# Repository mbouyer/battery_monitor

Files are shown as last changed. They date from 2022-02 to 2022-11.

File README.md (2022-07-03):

# battery_monitor
12V battery monitoring

This project includes 2 boards for a service 12V Pb battery monitoring.

The main board monitors the battery voltage and current, using a microchip PAC1953 chip and a precision shunt resistor. It uses a pic18f with integrated CAN controller, and connects to a CAN bus network. Along with instant voltage and current values, the pic18f will be able to compute and report the battery SoC. As the PAC1953 has 3 channels, it will also be able to monitor other sources, like solar panel or the engine battery. The main battery will be monitored with an external, high current shunt resistor (100A/50mV) so one of the on-board shunt resitor won't be soldered.

The second board will convert the voltage across the high current shunt resistor to a voltage (between 0.5 and 4.5V) suitable to drive a pannel-mounted Osculati  +/-50A ampmeter(27.320.23). As I don't expect to have currents more than 20A here, I computed the gain so that the indicator range is +/-25A (that is, the indicated value will be twice the real value). Two potentiometers allows to adjust the 0 and the gain. This, along with an external analog voltmeter, provides a second, independant battery monitoring tool.

car battery, engine and solar panel icons by [Icons8](https://icons8.com)

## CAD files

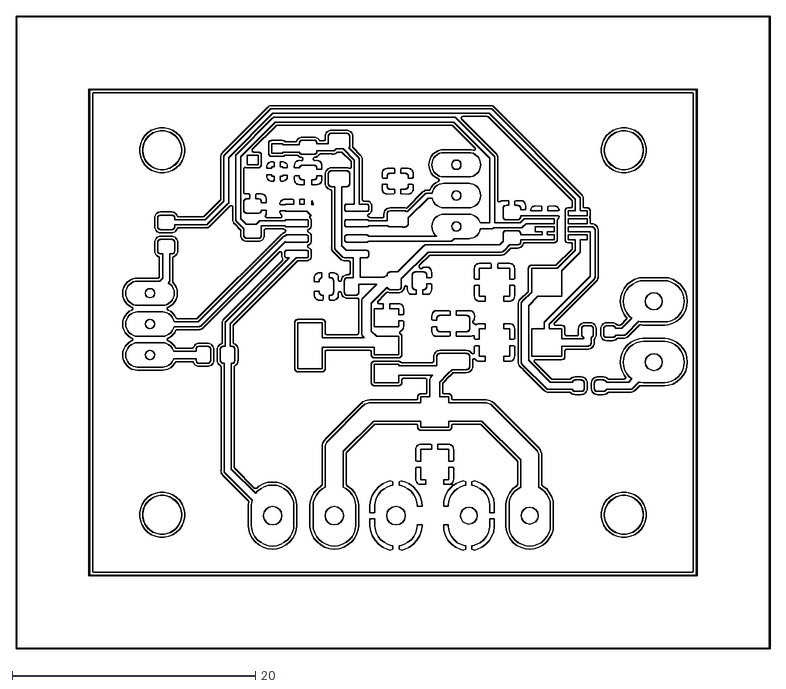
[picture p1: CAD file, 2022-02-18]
hardware/CAD/osculati_amperemetre_sensor-B_Cu.dxf
62.1 x 52.1

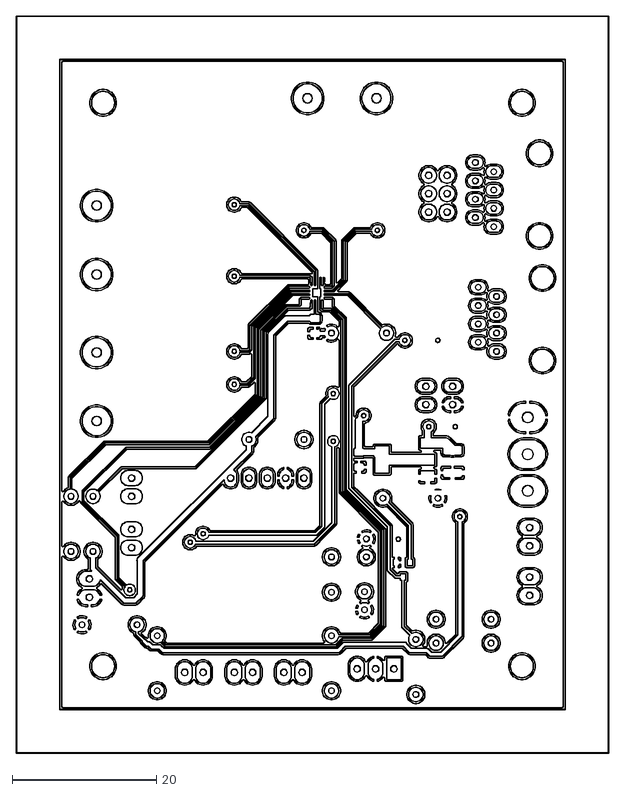
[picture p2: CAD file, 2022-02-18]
hardware/CAD/battery_can_monitor-F_Cu.dxf
82.1 x 102.1

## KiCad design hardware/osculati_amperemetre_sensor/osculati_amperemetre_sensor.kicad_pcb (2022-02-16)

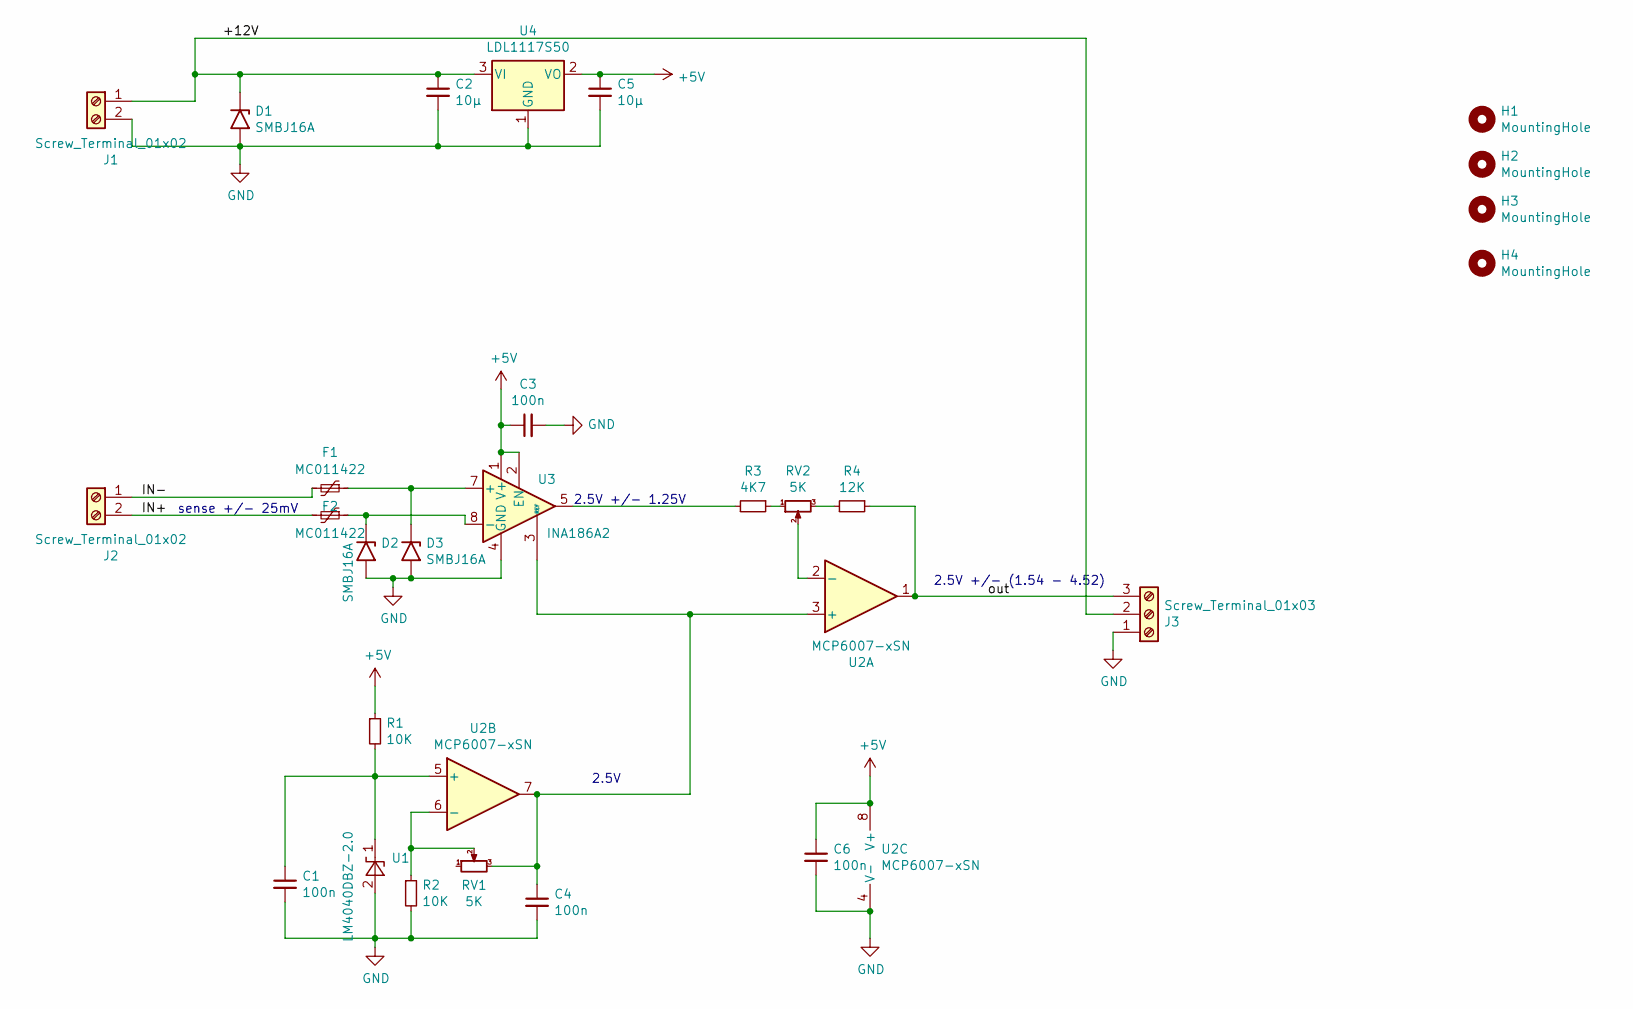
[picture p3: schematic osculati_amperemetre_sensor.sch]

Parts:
C1, C3, C4, C6: 100n; C_0805_2012Metric_Pad1.18x1.45mm_HandSolder
C2: 10µ; C_1210_3225Metric_Pad1.33x2.70mm_HandSolder
C5: 10µ; C_0805_2012Metric_Pad1.18x1.45mm_HandSolder
D1, D2, D3: SMBJ16A; D_SMB
F1, F2: MC011422; R_0603_1608Metric_Pad0.98x0.95mm_HandSolder
H1, H2, H3, H4: MountingHole; MountingHole_3.2mm_M3_DIN965
J1, J2: Screw_Terminal_01x02; MC24356
J3: Screw_Terminal_01x03; TerminalBlock_bornier-3_P5.08mm
R1, R2: 10K; R_1206_3216Metric_Pad1.30x1.75mm_HandSolder
R3: 4K7; R_0805_2012Metric_Pad1.20x1.40mm_HandSolder
R4: 12K; R_0805_2012Metric_Pad1.20x1.40mm_HandSolder
RV1, RV2: 5K; T93XA
U1: LM4040DBZ-2.0; SOT-23
U2: MCP6007-xSN; SOIC-8_3.9x4.9mm_P1.27mm
U3: INA186A2; SOT-23-8_Handsoldering
U4: LDL1117S50; SOT-223-3_TabPin2

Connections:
+5V: C3.1, C5.1, C6.1, R1.1, U2.8 (V+), U3.1 (V+), U3.2 (EN), U4.2 (VO)
/+12V: C2.1, D1.1 (A1), J1.1, J3.2, U4.3 (VI)
/IN+: F2.2, J2.2
/IN-: F1.2, J2.1
/out: J3.3, R4.1, U2.1
GND: C1.2, C2.2, C3.2, C4.2, C5.2, C6.2, D1.2 (A2), D2.2 (A2), D3.2 (A2), J1.2, J3.1, R2.2, U1.2 (A), U2.4 (V-), U3.4 (GND), U4.1 (GND)
unnamed: C1.1, R1.2, U1.1 (K), U2.5 (+)
unnamed: C4.1, RV1.3, U2.3 (+), U2.7, U3.3 (REF)
unnamed: D2.1 (A1), F2.1, U3.8 (-)
unnamed: D3.1 (A1), F1.1, U3.7 (+)
unnamed: R2.1, RV1.2, U2.6 (-)
unnamed: R3.1, RV2.1
unnamed: R3.2, U3.5
unnamed: R4.2, RV2.3
unnamed: RV2.2, U2.2 (-)

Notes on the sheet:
sense +/- 25mV
2.5V
2.5V +/- 1.25V
2.5V +/- (1.54 - 4.52)

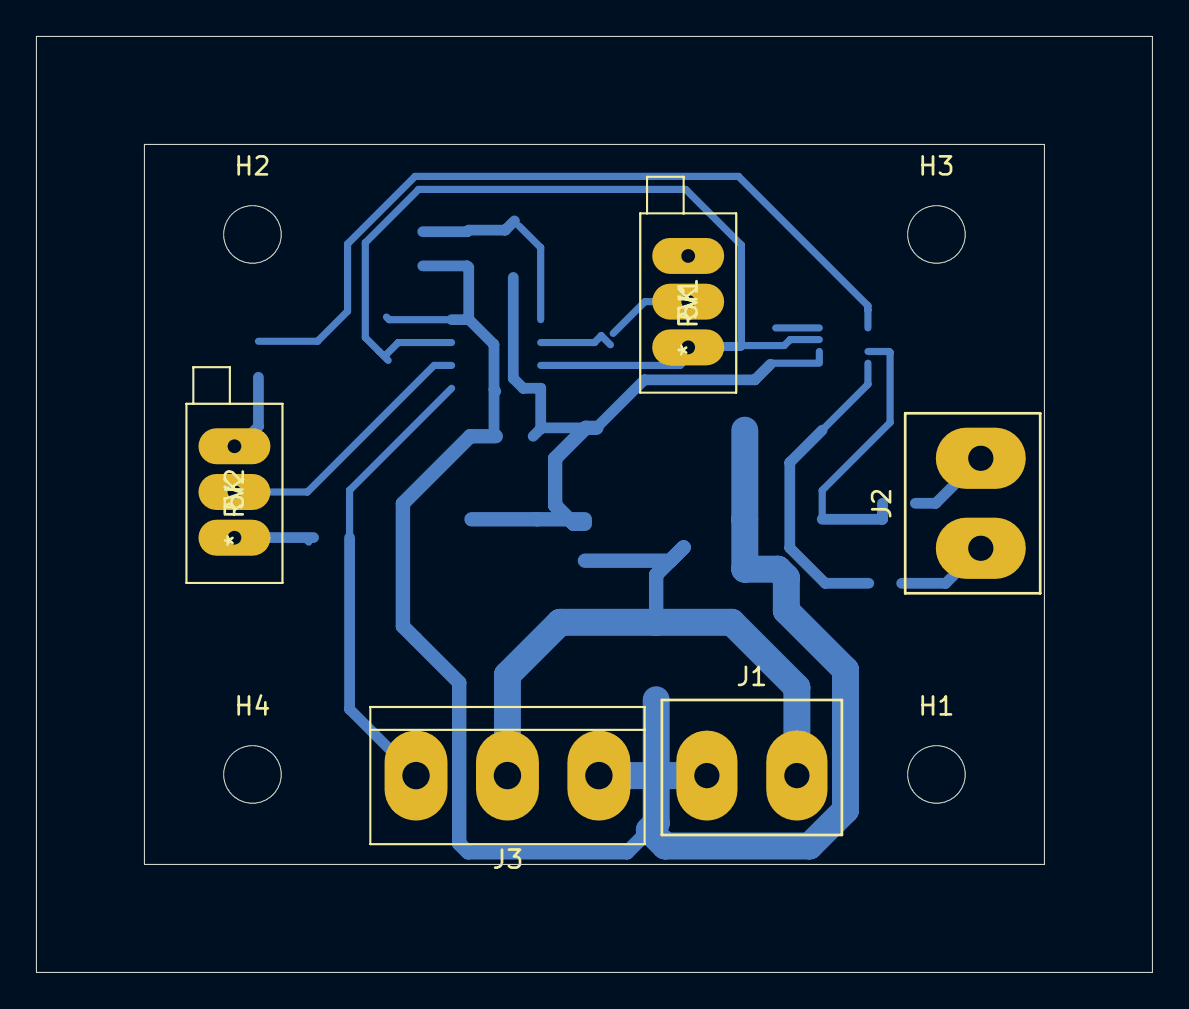
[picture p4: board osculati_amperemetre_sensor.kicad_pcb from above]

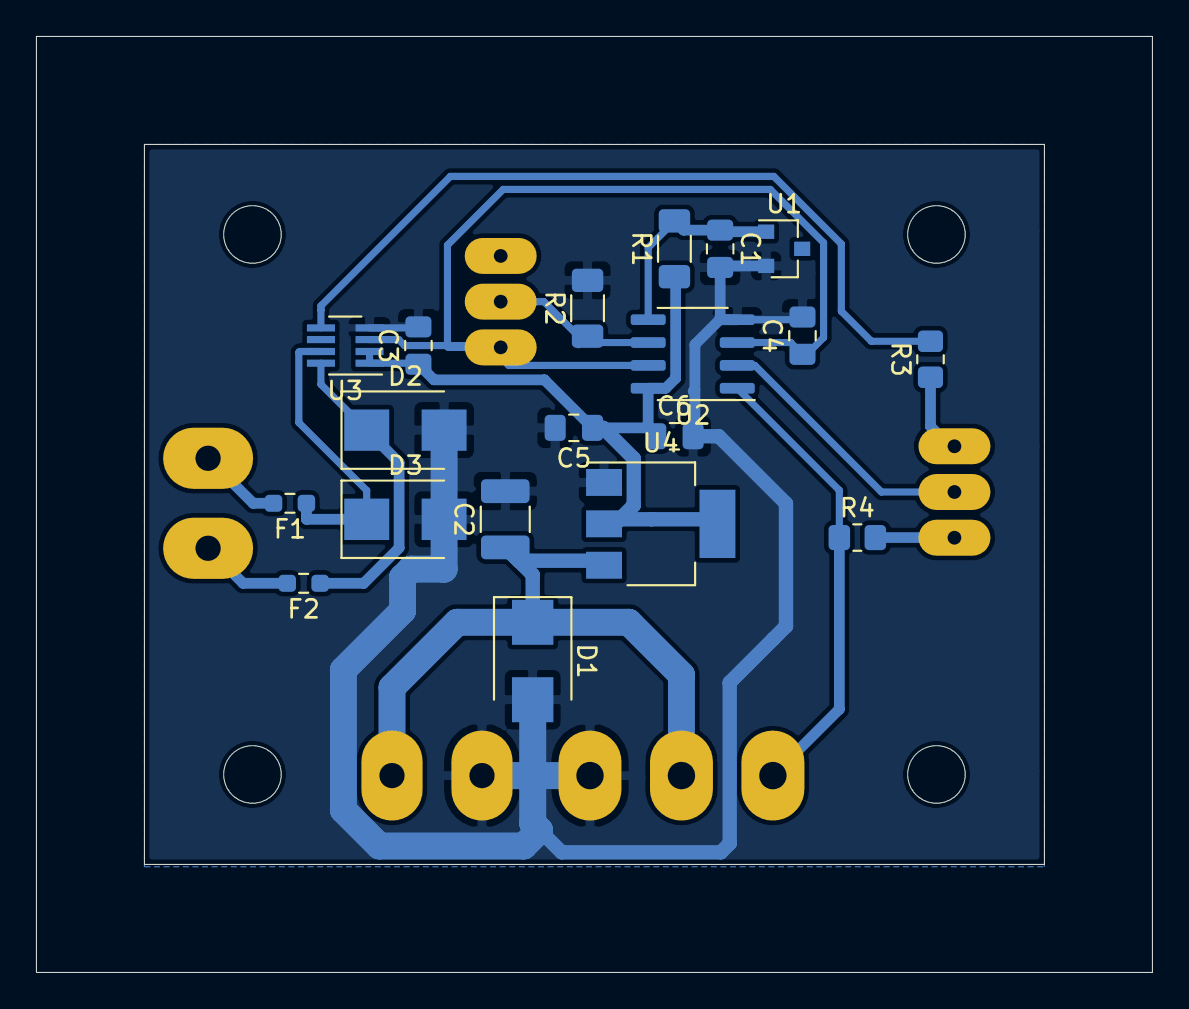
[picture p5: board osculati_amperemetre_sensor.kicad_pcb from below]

Board: 2 copper layers, 62.0 x 52.0 mm, 28 parts (19 on the bottom side), 15 nets.

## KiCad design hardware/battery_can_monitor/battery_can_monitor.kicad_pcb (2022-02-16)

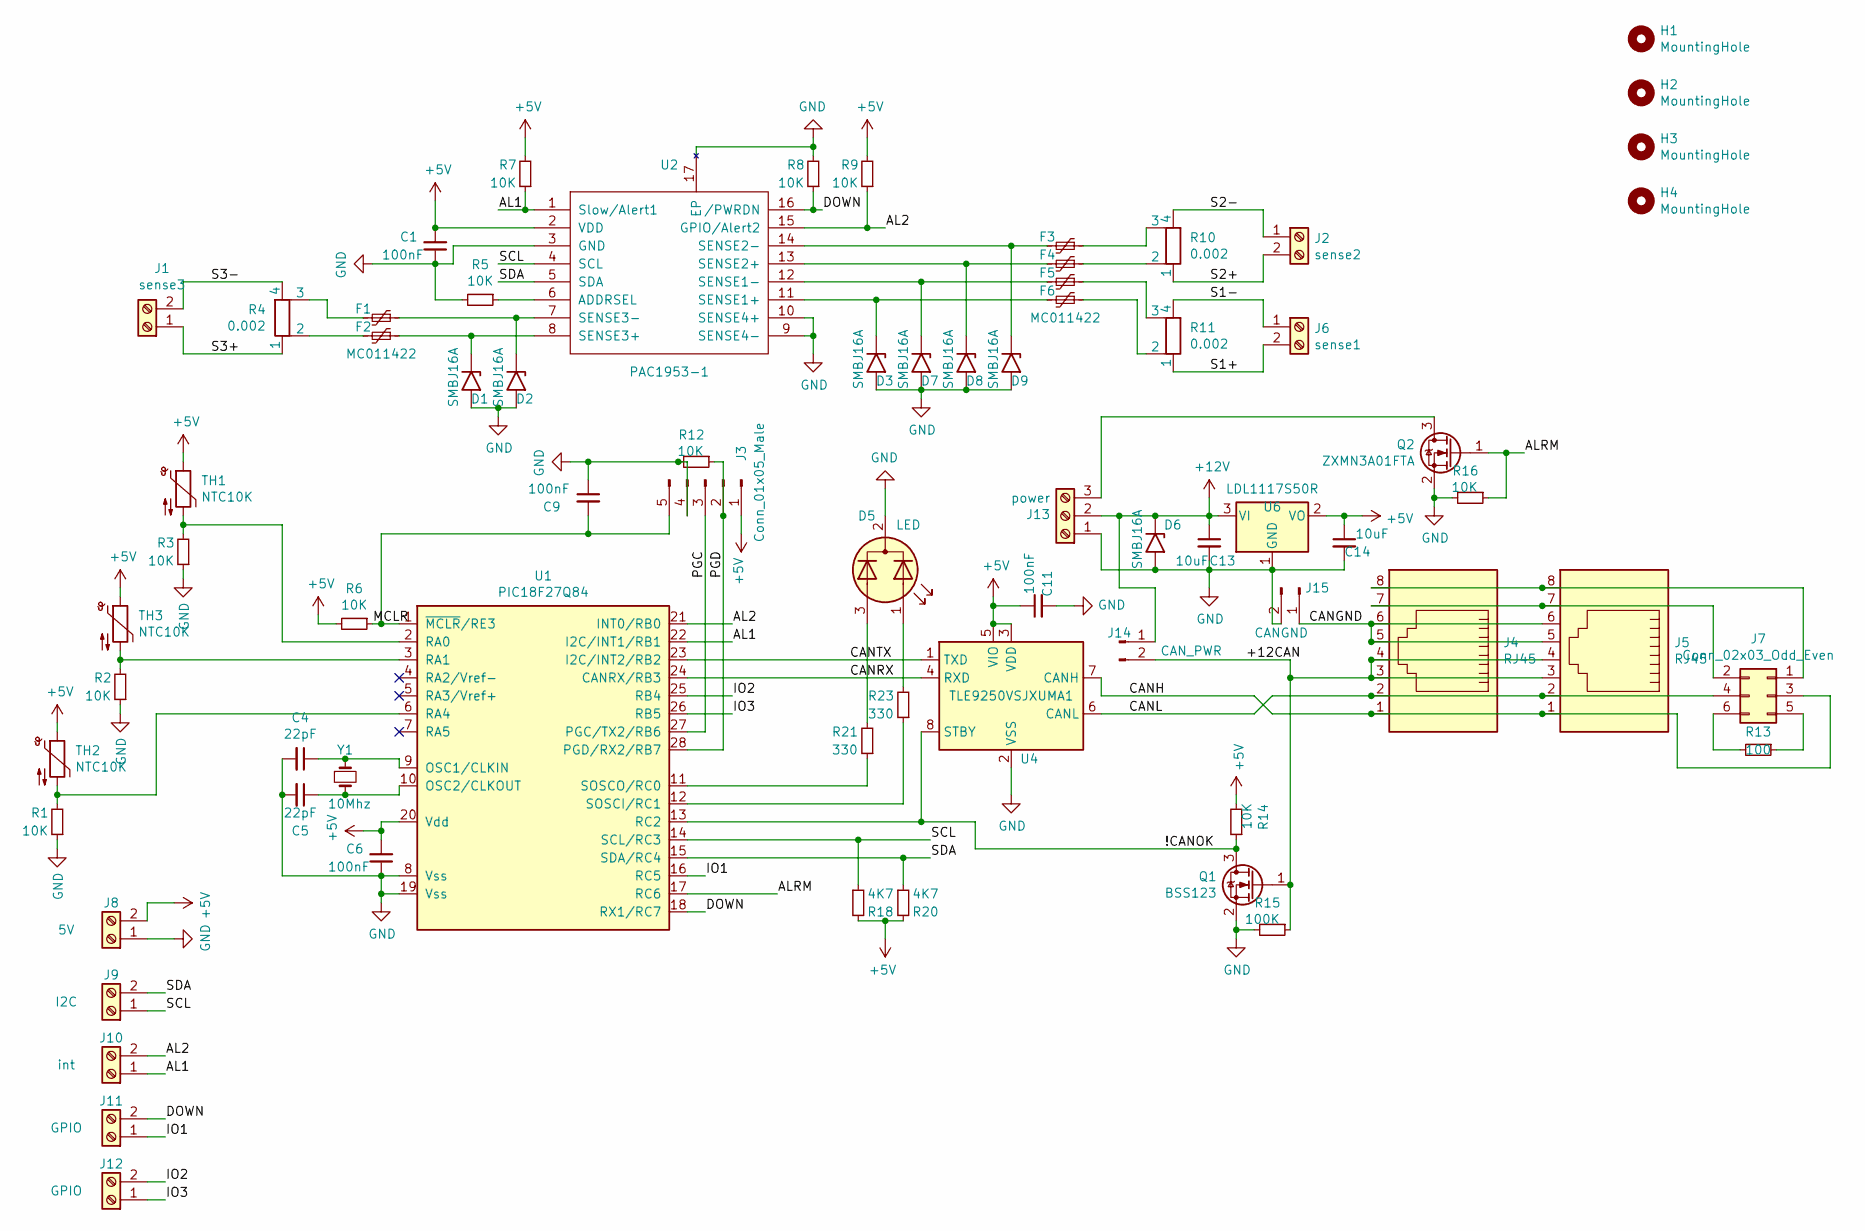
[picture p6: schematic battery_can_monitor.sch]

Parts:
C1, C6, C9, C11: 100nF; C_0805_2012Metric_Pad1.18x1.45mm_HandSolder
C4, C5: 22pF; C_Disc_D3.8mm_W2.6mm_P2.50mm
C13: 10uF; C_1210_3225Metric_Pad1.33x2.70mm_HandSolder
C14: 10uF; C_0805_2012Metric_Pad1.18x1.45mm_HandSolder
D1, D2, D3, D6, D7, D8, D9: SMBJ16A; D_SMB_Handsoldering
D5: LED; LED_D3.0mm-3
F1, F2, F3, F4, F5, F6: MC011422; R_0603_1608Metric_Pad0.98x0.95mm_HandSolder
H1, H2, H3, H4: MountingHole; MountingHole_3.2mm_M3_DIN965
J1: sense3; TerminalBlock_MetzConnect_Type703_RT10N02HGLU_1x02_P9.52mm_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
J2: sense2; TerminalBlock_MetzConnect_Type703_RT10N02HGLU_1x02_P9.52mm_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
J3: Conn_01x05_Male; PinHeader_1x05_P2.54mm_Vertical
J4, J5: RJ45; RJ45_Amphenol_54602-x08_Horizontal
J6: sense1; TerminalBlock_MetzConnect_Type703_RT10N02HGLU_1x02_P9.52mm_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
J7: Conn_02x03_Odd_Even; PinHeader_2x03_P2.54mm_Vertical
J8: 5V; TerminalBlock_TE_282834-2_1x02_P2.54mm_Horizontal
J9: I2C; TerminalBlock_TE_282834-2_1x02_P2.54mm_Horizontal
J10: int; TerminalBlock_TE_282834-2_1x02_P2.54mm_Horizontal
J11, J12: GPIO; TerminalBlock_TE_282834-2_1x02_P2.54mm_Horizontal
J13: power; TerminalBlock_bornier-3_P5.08mm
J14: CAN_PWR; PinHeader_1x02_P2.54mm_Vertical
J15: CANGND; PinHeader_1x02_P2.54mm_Vertical
Q1: BSS123; SOT-23
Q2: ZXMN3A01FTA; SOT-23
R1, R2, R3, R8, R12: 10K; R_1206_3216Metric_Pad1.30x1.75mm_HandSolder
R4, R10, R11: 0.002; R-Shunt_2512_6332Metric_Pad1.40x3.35mm_HandSolder
R5, R6, R7, R9, R14, R16: 10K; R_Axial_DIN0207_L6.3mm_D2.5mm_P7.62mm_Horizontal
R13: 100; R_0805_2012Metric_Pad1.20x1.40mm_HandSolder
R15: 100K; R_Axial_DIN0207_L6.3mm_D2.5mm_P7.62mm_Horizontal
R18, R20: 4K7; R_Axial_DIN0207_L6.3mm_D2.5mm_P7.62mm_Horizontal
R21, R23: 330; R_Axial_DIN0207_L6.3mm_D2.5mm_P7.62mm_Horizontal
TH1, TH2, TH3: NTC10K; TerminalBlock_TE_282834-2_1x02_P2.54mm_Horizontal
U1: PIC18F27Q84; SOIC-28W_7.5x17.9mm_P1.27mm
U2: PAC1953-1; VQFN-16-1EP_3x3mm_P0.5mm_EP1.1x1.1mm
U4: TLE9250VSJXUMA1; SOIC-8_3.9x4.9mm_P1.27mm
U6: LDL1117S50R; SOT-223-3_TabPin2
Y1: 10Mhz; Crystal_HC18-U_Vertical

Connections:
+5V: C1.2, C6.2, C11.1, C14.1, J3.1, J8.2, R6.2, R7.2, R9.2, R14.2, R18.2, R20.2, TH1.1, TH2.1, TH3.1, U1.20 (Vdd), U2.2 (VDD), U4.3 (VDD), U4.5 (VIO), U6.2 (VO)
+12V: C13.1, D6.1 (A1), J13.2, J14.1, U6.3 (VI)
/!CANOK: Q1.3 (D), R14.1, U1.13 (RC2), U4.8 (STBY)
/+12CAN: J4.3, J4.4, J5.3, J5.4, J14.2, Q1.1 (G), R15.1
/AL1: J10.1, R7.1, U1.22 (I2C/INT1/RB1), U2.1 (Slow/Alert1)
/AL2: J10.2, R9.1, U1.21 (INT0/RB0), U2.15 (GPIO/Alert2)
/ALRM: Q2.1 (G), R16.1, U1.17 (RC6)
/CANGND: J4.5, J4.6, J5.5, J5.6, J15.1
/CANH: J4.1, J5.1, J7.3, U4.7 (CANH)
/CANL: J4.2, J5.2, J7.4, U4.6 (CANL)
/CANRX: U1.24 (CANRX/RB3), U4.4 (RXD)
/CANTX: U1.23 (I2C/INT2/RB2), U4.1 (TXD)
/DOWN: J11.2, R8.1, U1.18 (RX1/RC7), U2.16 (/PWRDN)
/IO1: J11.1, U1.16 (RC5)
/IO2: J12.2, U1.25 (RB4)
/IO3: J12.1, U1.26 (RB5)
/MCLR: C9.2, J3.5, R6.1, U1.1 (~MCLR~/RE3)
/PGC: J3.3, U1.27 (PGC/TX2/RB6)
/PGD: J3.2, R12.1, U1.28 (PGD/RX2/RB7)
/S1+: J6.2, R11.1
/S1-: J6.1, R11.4
/S2+: J2.2, R10.1
/S2-: J2.1, R10.4
/S3+: J1.1, R4.1
/S3-: J1.2, R4.4
/SCL: J9.1, R18.1, U1.14 (SCL/RC3), U2.4 (SCL)
/SDA: J9.2, R20.1, U1.15 (SDA/RC4), U2.5 (SDA)
GND: C1.1, C4.2, C5.2, C6.1, C9.1, C11.2, C13.2, C14.2, D1.2 (A2), D2.2 (A2), D3.2 (A2), D5.2 (K), D6.2 (A2), D7.2 (A2), D8.2 (A2), D9.2 (A2), J3.4, J8.1, J13.1, J15.2, Q1.2 (S), Q2.2 (S), R1.1, R2.1, R3.1, R5.2, R8.2, R12.2, R15.2, R16.2, U1.8 (Vss), U1.19 (Vss), U2.3 (GND), U2.9 (SENSE4-), U2.10 (SENSE4+), U2.17 (EP), U4.2 (VSS), U4.9 (VSS), U6.1 (GND)
unnamed: C4.1, U1.9 (OSC1/CLKIN), Y1.1
unnamed: C5.1, U1.10 (OSC2/CLKOUT), Y1.2
unnamed: D1.1 (A1), F2.1, U2.8 (SENSE3+)
unnamed: D2.1 (A1), F1.1, U2.7 (SENSE3-)
unnamed: D3.1 (A1), F6.2, U2.11 (SENSE1+)
unnamed: D5.1 (A1), R23.2
unnamed: D5.3 (A2), R21.2
unnamed: D7.1 (A1), F5.2, U2.12 (SENSE1-)
unnamed: D8.1 (A1), F4.2, U2.13 (SENSE2+)
unnamed: D9.1 (A1), F3.2, U2.14 (SENSE2-)
unnamed: F1.2, R4.3
unnamed: F2.2, R4.2
unnamed: F3.1, R10.3
unnamed: F4.1, R10.2
unnamed: F5.1, R11.3
unnamed: F6.1, R11.2
unnamed: J4.7, J5.7, J7.2
unnamed: J4.8, J5.8, J7.1
unnamed: J7.5, R13.1
unnamed: J7.6, R13.2
unnamed: J13.3, Q2.3 (D)
unnamed: R1.2, TH2.2, U1.6 (RA4)
unnamed: R2.2, TH3.2, U1.3 (RA1)
unnamed: R3.2, TH1.2, U1.2 (RA0)
unnamed: R5.1, U2.6 (ADDRSEL)
unnamed: R21.1, U1.11 (SOSCO/RC0)
unnamed: R23.1, U1.12 (SOSCI/RC1)

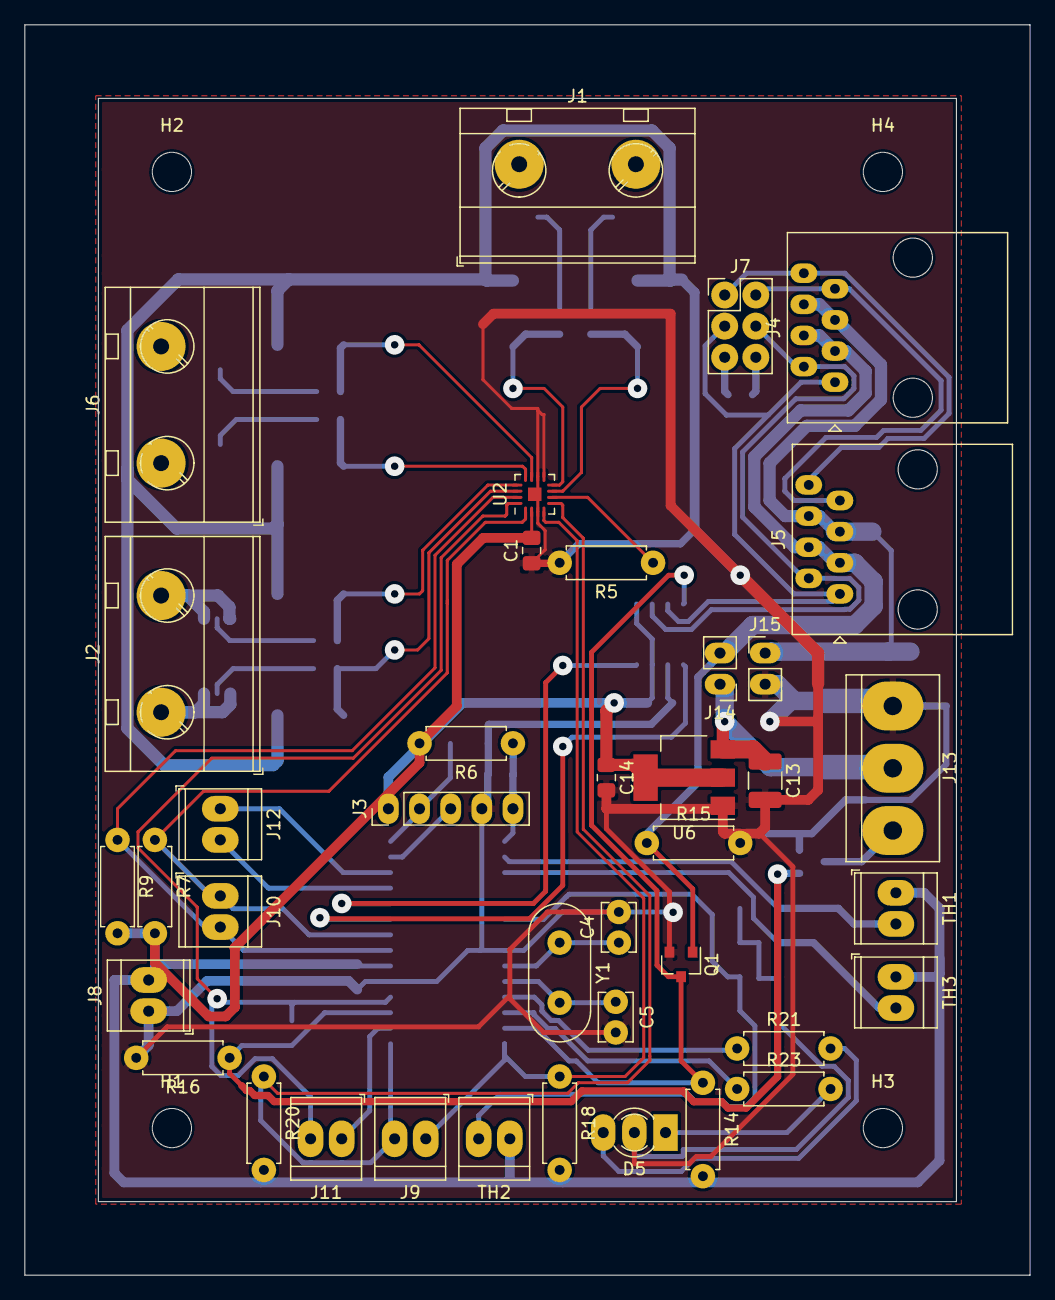
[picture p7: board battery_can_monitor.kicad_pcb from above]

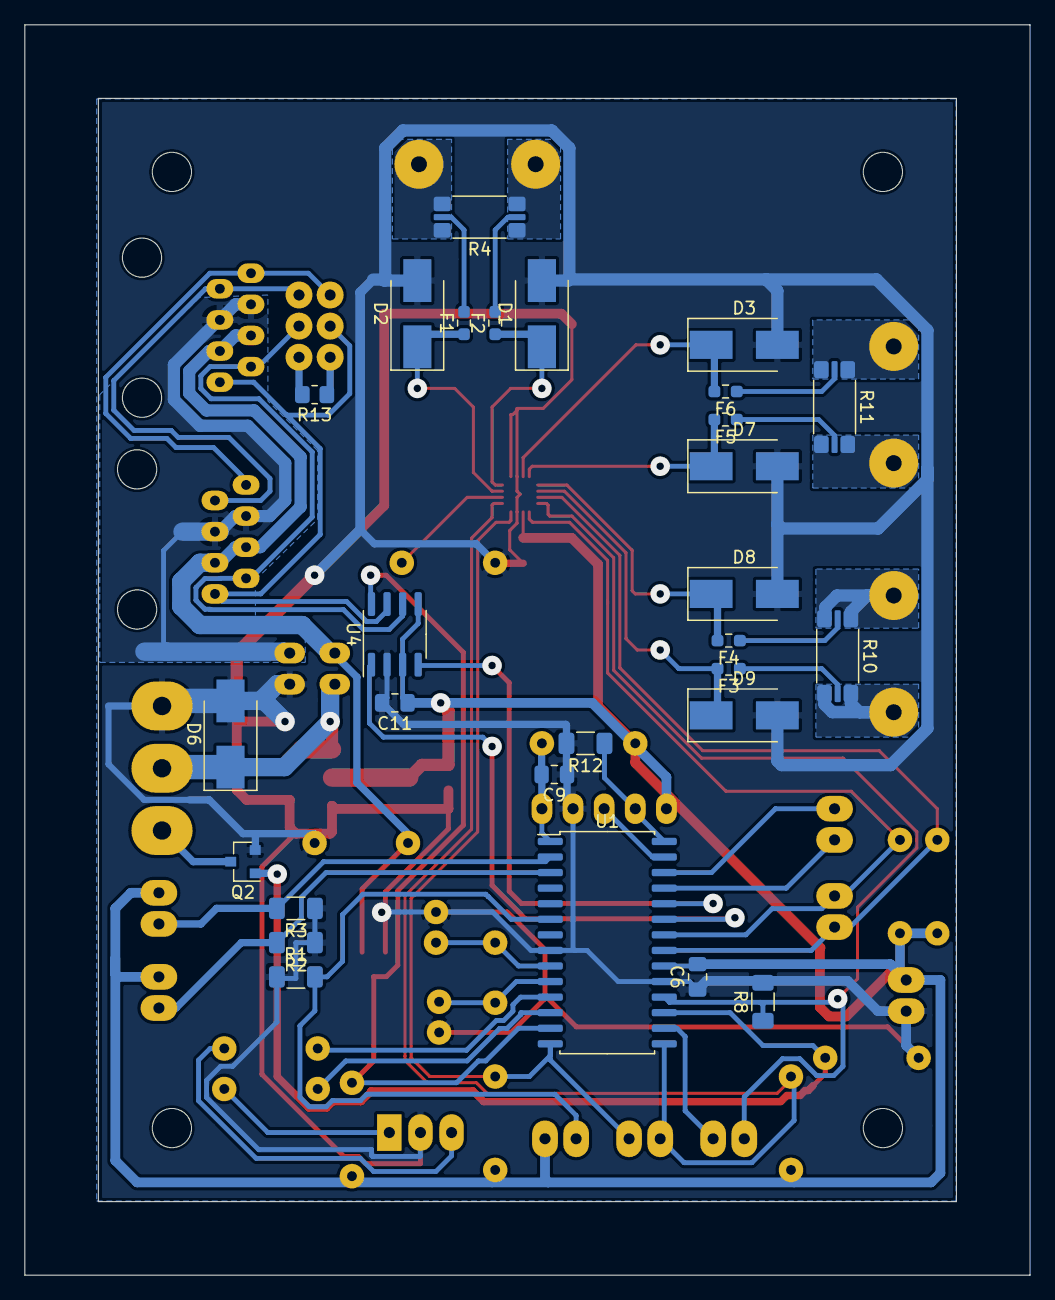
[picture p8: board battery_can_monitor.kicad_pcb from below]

Board: 2 copper layers, 82.0 x 102.0 mm, 71 parts (28 on the bottom side), 55 nets.

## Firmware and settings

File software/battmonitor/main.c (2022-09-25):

/* $Id: main.c,v 1.36 2019/03/12 19:24:19 bouyer Exp $ */
/*
 * Copyright (c) 2022 Manuel Bouyer
 *
 * All rights reserved.
 *
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
 * THIS SOFTWARE IS PROVIDED BY THE NETBSD FOUNDATION, INC. AND CONTRIBUTORS
 * ``AS IS'' AND ANY EXPRESS OR IMPLIED WARRANTIES, INCLUDING, BUT NOT LIMITED
 * TO, THE IMPLIED WARRANTIES OF MERCHANTABILITY AND FITNESS FOR A PARTICULAR
 * PURPOSE ARE DISCLAIMED.  IN NO EVENT SHALL THE FOUNDATION OR CONTRIBUTORS
 * BE LIABLE FOR ANY DIRECT, INDIRECT, INCIDENTAL, SPECIAL, EXEMPLARY, OR
 * CONSEQUENTIAL DAMAGES (INCLUDING, BUT NOT LIMITED TO, PROCUREMENT OF
 * SUBSTITUTE GOODS OR SERVICES; LOSS OF USE, DATA, OR PROFITS; OR BUSINESS
 * INTERRUPTION) HOWEVER CAUSED AND ON ANY THEORY OF LIABILITY, WHETHER IN
 * CONTRACT, STRICT LIABILITY, OR TORT (INCLUDING NEGLIGENCE OR OTHERWISE)
 * ARISING IN ANY WAY OUT OF THE USE OF THIS SOFTWARE, EVEN IF ADVISED OF THE
 * POSSIBILITY OF SUCH DAMAGE.
 */

#include <xc.h>
#include <stdio.h> 
#include <string.h> 
#include <stdlib.h> 
#include <nmea2000.h>
#include <nmea2000_pgn.h>
#include <raddeg.h>
#include "serial.h"
#include "i2c.h"
#include "ntc_tab.h"
#include "pac195x.h"

unsigned int devid, revid; 

unsigned long nmea2000_user_id; 

static unsigned char sid;

static struct nmea2000_msg msg;
static unsigned char nmea2000_data[NMEA2000_DATA_FASTLENGTH];

unsigned int timer0_read(void);

#define TIMER0_5MS 48
#define TIMER0_1MS 10

#define LEDBATT_R LATCbits.LATC0
#define LEDBATT_G LATCbits.LATC1

#define NDOWN LATCbits.LATC7
#define NCANOK PORTCbits.RC2

static char counter_10hz;
static char counter_1hz;
static uint16_t seconds;
static volatile union softintrs {
	struct softintrs_bits {
		char int_10hz : 1;	/* 0.1s timer */
	} bits;
	char byte;
} softintrs;

static uint16_t a2d_acc;

#define PAC_I2C_ADDR 0x2e

int16_t batt_v[4];
int16_t batt_i[4];
uint16_t batt_temp[4];

static int32_t voltages_acc[4];
pac_ctrl_t pac_ctrl;

/* for journal */
static int64_t l600_current_acc[4];
static __uint24 l600_current_count;
static uint32_t l600_voltages_acc[4];

/*
 * journal data structure (record every 10mn)
 * For current, in mA: 18 bits, including sign
 * voltage, max 20.47V needs 11 bits
 * temperature -40C to 60C: 8 bits (K - 233)
 * valid: 1bit
 * instance: 2 bits
 =>  total 40 bits, or 5 bytes
 51 entries per block of 256 bytes: 1 bytes free (for block flags)
 In 32k flash, 128 blocks -> 6528 entries, or 272 hours (11 days)
   with 4 channels active
 */

union log_entry {
	uint8_t data[5];
	struct {
		uint8_t temp;
		uint8_t u_low; /* low bits of voltage */
		uint16_t i_low; /* low bits current */
		uint8_t u_high : 3; /* high bits of voltage */
		uint8_t nvalid : 1; /* 0 = entry valid */
		uint8_t i_high: 2; /* high bits of current */
		uint8_t instance: 2; /* batt instance */
	} s;
};

#define LOG_ENTRIES 51

struct log_block {
	union log_entry b_entry[LOG_ENTRIES];
	uint8_t b_flags;
#define B_FILL_STAT 0x03
#define B_FILL_FREE 0x03
#define B_FILL_PART 0x01
#define B_FILL_FULL 0x00
#define B_FILL_GEN  0xfc
};

#define LOG_BLOCKS ((uint8_t)128)
#define LOG_BLOCKS_MASK (LOG_BLOCKS - 1)

extern const struct log_block battlog[LOG_BLOCKS] __at(0x18000);

extern struct log_block curlog __at(0x3700);

/* current log entry (to be updated) */
uint8_t log_cblk;
uint8_t log_centry;
uint8_t log_gen;

/* log requests/replies */
uint8_t logreq_len;
uint8_t logreq_id; /* current id for fast frame */

union __packed {
	uint8_t _data[233 + 8];
	struct private_log_request rq;
	struct private_log_reply rp;
	struct private_log_error er;
	struct private_log_reset rst;
} private_log_cmd;
static unsigned char fastid;

static inline void
utolog(uint16_t u, union log_entry *e)
{
	e->s.u_low = u & 0xff;
	e->s.u_high = (u >> 8) & 0x7;
}

static inline uint16_t
logtou(union log_entry *e)
{
	uint16_t u;

	u = e->s.u_low;
	u |= (uint16_t)(e->s.u_high & 0x7) << 8;
	return u;
}

static inline void
itolog(int64_t i, union log_entry *e)
{
	e->s.i_low = i & 0xffff;
	e->s.i_high = (i >> 16) & 0x3;
}

static inline int32_t
logtoi(union log_entry *e)
{
	int32_t i;
	i = e->s.i_low;
	i |= (uint32_t)(e->s.i_high & 0x3) << 16;
	if (e->s.i_high & 0x2) {
		i |= 0xfffe0000;
	}
	return i;
}

static void
page_erase(__uint24 addr)
{
	uint8_t err = 0;

	printf("erase 0x%lx\n", (uint32_t)addr);

	NVMADR = addr;
	NVMCON1bits.CMD = 0x06;
	INTCON0bits.GIE = 0;

	NVMLOCK = 0x55;
	NVMLOCK = 0xAA;
	NVMCON0bits.GO = 1;

	while (NVMCON0bits.GO)
		; /* wait */

	if (NVMCON1bits.WRERR) {
		err++;
	}
	NVMCON1bits.CMD = 0;
	INTCON0bits.GIE = 1;
	if (err) {
		printf("erase 0x%lx failed\n", (uint32_t)addr);
	}
}

static void
page_read(__uint24 addr)
{
	uint8_t err = 0;

	printf("read 0x%lx\n", (uint32_t)addr);

	NVMADR = addr;
	NVMCON1bits.CMD = 0x02;
	NVMCON0bits.GO = 1;

	while (NVMCON0bits.GO)
		; /* wait */

	NVMCON1bits.CMD = 0;
}

static void
page_write(__uint24 addr)
{
	uint8_t err = 0;

	printf("write 0x%lx\n", (uint32_t)addr);

	NVMADR = addr;
	NVMCON1bits.CMD = 0x05;
	INTCON0bits.GIE = 0;

	NVMLOCK = 0x55;
	NVMLOCK = 0xAA;
	NVMCON0bits.GO = 1;

	while (NVMCON0bits.GO)
		; /* wait */

	if (NVMCON1bits.WRERR) {
		err++;
	}
	NVMCON1bits.CMD = 0;
	INTCON0bits.GIE = 1;
	if (err) {
		printf("write 0x%lx failed\n", (uint32_t)addr);
	}
}

static void
next_log_entry(void)
{
	printf("write log entry %d/%d\n", log_cblk, log_centry);
	/* mark entry as valid */
	curlog.b_entry[log_centry].s.nvalid = 0;
	curlog.b_flags = log_gen | B_FILL_PART;
	log_centry++;
	if (log_centry == LOG_ENTRIES) {
		/* next block */
		/* write current block */
		curlog.b_flags = log_gen | B_FILL_FULL;
		page_write(&battlog[log_cblk]);
		/* point to next block */
		log_cblk = (log_cblk + 1) & LOG_BLOCKS_MASK;
		log_centry = 0;
		if (log_cblk == 0) /* rollover; update gen number */
			log_gen += 0x4;
		/* erase and load new block */
		page_erase(&battlog[log_cblk]);
		page_read(&battlog[log_cblk]);
	} else {
		/* update current block */
		page_write(&battlog[log_cblk]);
	}
}

static void
log_erase(void)
{
	for (uint8_t c = 0; c < LOG_BLOCKS; c++) {
		page_erase(&battlog[c]);
	}
	log_cblk = log_centry = log_gen = 0;
}

static void
update_log(void)
{
	char c;
	double v;
	int32_t v_i;

	for (c = 0; c < 4; c++) {
		printf("log entry %d/%d ", log_cblk, log_centry);
		if ((pac_ctrl.ctrl_chan_dis & (8 >> c)) != 0)
			continue;
		/* batt_i = acc_value * 0.00075 * 1000 */
		v = (double)l600_current_acc[c] * 0.75 / l600_current_count;
		/* adjust with calibration data */
		switch(c) {
		case 0:
			v = v * 0.988689144013892;
			break;
		case 1:
			v = v * 1.00930129713152;
			break;
		case 2:
			v = v * 4.06331342566096;
			break;
		}
		v_i = v + 0.5;
		printf(" %d %4.4fA %ld", c, v / 1000, v_i);
		itolog(v_i, &curlog.b_entry[log_centry]);
		/* volt = vbus * 0.000488 */
		/* batt_v = voltages_acc * 0.000488 * 100 / 6000; */
		/* adjust by 0.99955132 from calibration data */
		v = (double)l600_voltages_acc[c] * 0.000008129684;
		v_i = v + 0.5;
		printf(" %4.3fV %ld", v / 100, v_i);
		utolog(v_i, &curlog.b_entry[log_centry]);
		curlog.b_entry[log_centry].s.instance = c;
		if (batt_temp[c] == 0xffff) {
			curlog.b_entry[log_centry].s.temp = 0xff;
		} else {
			curlog.b_entry[log_centry].s.temp =
			    (uint8_t)((batt_temp[c] - 23300) / 100);
		}
		next_log_entry();
		l600_current_acc[c] = 0;
		l600_voltages_acc[c] = 0;
	}
	l600_current_count = 0;
}

static void
send_log_block(uint8_t sid, uint8_t page)
{
	uint8_t c, i, j, r = 0;

	printf("send page %d\n", page);

	c = 0;
	while (c < LOG_ENTRIES && r == 0) {
		fastid = (fastid + 1) & 0x7;
		msg.id.id = 0;
		msg.id.iso_pg = (PRIVATE_LOG >> 8) & 0xff;
		msg.id.daddr = rid.saddr;
		msg.id.priority = NMEA2000_PRIORITY_ACK;
		msg.dlc = sizeof(struct private_log_reply);
		private_log_cmd.rp.cmd = PRIVATE_LOG_REPLY;
		msg.data = &private_log_cmd.rp;
		private_log_cmd.rp.sid = sid;
		private_log_cmd.rp.idx =
		   ((uint16_t)(battlog[page].b_flags & B_FILL_GEN) << 8) | page;
		for (i = 0; c < LOG_ENTRIES; c++) {
			if (battlog[page].b_entry[c].s.nvalid == 1) {
				printf("page %d entry %d !valid\n", page, c);
				private_log_cmd.rp.idx |= 0x100;
				r++;
				break;
			}
			for (j = 0; j < sizeof(union log_entry); j++) {
				private_log_cmd.rp.data[i] =
				    battlog[page].b_entry[c].data[j];
				i++; msg.dlc++;
			}
			if (msg.dlc >= (NMEA2000_DATA_FASTLENGTH - sizeof(union log_entry))) {
				c++;
				break;
			}
		}
		if (c == LOG_ENTRIES)
			private_log_cmd.rp.idx |= 0x100;
		printf("send fast len %d/%d, %d entries\n",
		    msg.dlc, i, c);
		if (! nmea2000_send_fast_frame(&msg, fastid))
			printf("send PRIVATE_LOG_REPLY failed\n");
	}
}

static void
send_log_error(uint8_t sid, uint8_t code)
{
	fastid = (fastid + 1) & 0x7;
	msg.id.id = 0;
	msg.id.iso_pg = (PRIVATE_LOG >> 8) & 0xff;
	msg.id.daddr = rid.saddr;
	msg.id.priority = NMEA2000_PRIORITY_ACK;
	msg.dlc = sizeof(struct private_log_error);
	msg.data = &private_log_cmd.er;
	private_log_cmd.er.cmd = PRIVATE_LOG_ERROR;
	private_log_cmd.er.sid = sid;
	private_log_cmd.er.error = code;
	if (! nmea2000_send_fast_frame(&msg, fastid))
		printf("send PRIVATE_LOG_ERROR failed\n");
}

static void
handle_log_request(uint8_t cmd) {
	uint8_t gen = (private_log_cmd.rq.idx & 0xff00) >> 8;
	uint8_t page = private_log_cmd.rq.idx & 0xff;
	uint8_t sid = private_log_cmd.rq.sid;
	uint8_t i;
	printf("log request sid %d gen %d page %d\n", sid, gen, page);

	if (cmd == PRIVATE_LOG_REQUEST_FIRST) {
		/* look for first log entry - usually next page */
		for (i = 0, page = (log_cblk + 1) & LOG_BLOCKS_MASK;
		    i < LOG_BLOCKS; 
		     page = (page + 1) & LOG_BLOCKS_MASK, i++) {
			if ((battlog[page].b_flags & B_FILL_STAT) !=
			    B_FILL_FREE)
				break;
		}
		if (i == LOG_BLOCKS) {
			/* all entries free (e.g. just after a reset) */
			send_log_error(sid, PRIVATE_LOG_ERROR_NOTFOUND);
			return;
		}
		send_log_block(sid, page);
		return;
	}
	/* look for gen/page */
	if ((battlog[page].b_flags & B_FILL_GEN) != gen ||
	    (battlog[page].b_flags & B_FILL_STAT) == B_FILL_FREE) {
		send_log_error(sid, PRIVATE_LOG_ERROR_NOTFOUND);
		return;
	}
	if (cmd == PRIVATE_LOG_REQUEST) {
		/* just send this page */
		send_log_block(sid, page);
		return;
	}
	/* send next page, if there is one */
	if (page == log_cblk) {
		/* this is the last page */
		send_log_error(sid, PRIVATE_LOG_ERROR_LAST);
		return;
	}
	page = (page + 1) & LOG_BLOCKS_MASK;
	if ((battlog[page].b_flags & B_FILL_STAT) == B_FILL_FREE) {
		/* next page is free, assume previous was the last */
		send_log_error(sid, PRIVATE_LOG_ERROR_LAST);
		return;
	}
	send_log_block(sid, page);
}

static void
adctotemp(unsigned char c)
{
	char i;
	for (i = 1; temps[i].val != 0; i++) {
		if (a2d_acc > temps[i].val) {
			batt_temp[c] = temps[i - 1].temp -
			((temps[i - 1].temp - temps[i].temp)  /
		         (temps[i - 1].val - temps[i].val)  * 
			 (temps[i - 1].val - a2d_acc));
			return;
		}
	} 
	batt_temp[c] = 0xffff;
}

static void
send_batt_status(char c)
{
	if (nmea2000_status != NMEA2000_S_OK)
		return;

	struct nmea2000_battery_status_data *data = (void *)&nmea2000_data[0];

	if ((pac_ctrl.ctrl_chan_dis & (8 >> c)) != 0)
		return;

	PGN2ID(NMEA2000_BATTERY_STATUS, msg.id);
	msg.id.priority = NMEA2000_PRIORITY_INFO;
	msg.dlc = sizeof(struct nmea2000_battery_status_data);
	msg.data = &nmea2000_data[0];
	data->voltage = batt_v[c];
	data->current = batt_i[c];
	data->temp = batt_temp[c];
	data->sid = sid;
	data->instance = c;
	if (! nmea2000_send_single_frame(&msg))
		printf("send NMEA2000_BATTERY_STATUS failed\n");
}

#if 0

static void
send_dc_status(void)
{
	struct nmea2000_dc_status_data *data = (void *)&nmea2000_data[0];
	static unsigned char fastid;

	if (input_volt == 0xffff)
		return;

	fastid = (fastid + 1) & 0x7;
	printf("power voltage %d.%03dV\n",
	    (int)(input_volt / 1000), (int)(input_volt % 1000));

	PGN2ID(NMEA2000_DC_STATUS, msg.id);
	msg.id.priority = NMEA2000_PRIORITY_INFO;
	msg.dlc = sizeof(struct nmea2000_dc_status_data);
	msg.data = &nmea2000_data[0];
	data->sid = sid;
	data->instance = 0;
	switch(power_status) {
	case UNKOWN:
		return;
	case OFF:
		data->type = DCSTAT_TYPE_BATT;
		if (batt_v > 1240) {
			data->soc = 100 - ((unsigned long)time_on_batt * 100UL / 7200UL);
		} else {
			data->soc = 50 - (1240 - batt_v) * 50 / (1240 - 1100);
		}
		data->soh = 0xff;
		data->timeremain = 0xffff; /* XXX compute */
		data->ripple = 0xffff;
		break;
	default:
		/* assume operating on mains power */
		data->type = DCSTAT_TYPE_CONV;
		data->soc = 0xff;
		data->soh =
		    ((unsigned long)input_volt * 100UL + 6000UL) / 12000;
		data->timeremain = 0xffff;
		data->ripple = 0xffff;
		break;
	}
	if (! nmea2000_send_fast_frame(&msg, fastid))
		printf("send NMEA2000_DC_STATUS failed\n");
}

static void
send_charger_status()
{
	struct nmea2000_charger_status_data *data = (void *)&nmea2000_data[0];

	PGN2ID(NMEA2000_CHARGER_STATUS, msg.id);
	msg.id.priority = NMEA2000_PRIORITY_INFO;
	msg.dlc = sizeof(struct nmea2000_charger_status_data);
	msg.data = &nmea2000_data[0];
	data->instance = 0;
	data->batt_instance = 0;
	data->op_state = charger_status;
	data->mode = CHARGER_MODE_STANDALONE;
	data->enable = 1;
	data->eq_pending = 0;
	data->eq_time_remain = 0;
	if (! nmea2000_send_single_frame(&msg))
		printf("send NMEA2000_CHARGER_STATUS failed\n");
}
#endif

void
user_handle_iso_request(unsigned long pgn)
{
	printf("ISO_REQUEST for %ld from %d\n", pgn, rid.saddr);
	switch(pgn) {
	case NMEA2000_BATTERY_STATUS:
		for (char c = 0; c < 4; c++) {
			if ((pac_ctrl.ctrl_chan_dis & (8 >> c)) == 0)
				send_batt_status(c);
		}
		break;
#if 0
	case NMEA2000_DC_STATUS:
		send_dc_status();
		break;
	case NMEA2000_CHARGER_STATUS:
		send_charger_status();
		break;
#endif
	}
}
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
int
main(void)
{
	char c;
	uint8_t i2cr;
	pac_accumcfg_t pac_accumcfg;
	pac_neg_pwr_fsr_t pac_neg_pwr_fsr;
	static unsigned int poll_count;
	uint16_t t0;
	static int32_t voltages_acc_cur[4];
	uint8_t new_boot;


	devid = 0;
	revid = 0;
	nmea2000_user_id = 0;
	/* read devid and user IDs */
	TBLPTR = 0x200000;
	asm("tblrd*+;");
	asm("movff TABLAT, _nmea2000_user_id;");
	asm("tblrd*+;");
	asm("movff TABLAT, _nmea2000_user_id + 1;");
	TBLPTR = 0x3ffffc;
	asm("tblrd*+;");
	asm("movff TABLAT, _revid;");
	asm("tblrd*+;");
	asm("movff TABLAT, _revid + 1;");
	asm("tblrd*+;");
	asm("movff TABLAT, _devid;");
	asm("tblrd*+;");
	asm("movff TABLAT, _devid + 1;");

	/* disable unused modules */
	PMD0 = 0x7a; /* keep clock and IOC */
#ifdef USE_TIMER2
	PMD1 = 0xfa; /* keep timer0/timer2 */
	PMD2 = 0x03; /* keep can module */
#else
	PMD1 = 0xfe; /* keep timer0 */
	PMD2 = 0x02; /* keep can module, TU16A */
#endif
	PMD3 = 0xdf; /* keep ADC */
	PMD4 = 0xff;
	PMD5 = 0xff;
	PMD6 = 0xf6; /* keep UART1 and I2C */
	PMD7 = 0xff;
	PMD8 = 0xff;

	ANSELC = 0;
	LEDBATT_G = LEDBATT_R = NDOWN = 0;
	TRISCbits.TRISC0 = TRISCbits.TRISC1 = TRISCbits.TRISC7 = 0;
	LEDBATT_R = 1;

	ANSELB = 0;
	/* CANRX on RB3 */
	CANRXPPS = 0x0B;
	/* CANTX on RB2 */
	LATBbits.LATB2 = 1; /* output value when idle */
	TRISBbits.TRISB2 = 0;
	RB2PPS = 0x46;

	LATCbits.LATC5 = TRISCbits.TRISC5 = 0; /* IO1 */
	LATBbits.LATB4 = TRISBbits.TRISB4 = 0; /* IO2 */
	LATBbits.LATB5 = TRISBbits.TRISB5 = 0; /* IO3 */

	ANSELA = 0x13; /* RA0, RA1 and RA4 analog */
	LATA = 0;
	TRISA = 0xD3; /* RA2, RA3, RA5 as outpout */

	/* configure watchdog timer for 2s */
	WDTCON0 = 0x16;
	WDTCON1 = 0x07;

	/* configure sleep mode: PRI_IDLE */
	CPUDOZE = 0x80;

	softintrs.byte = 0;
	counter_10hz = 25;
	counter_1hz = 10;
	seconds = 0;

	for (c = 0; c < 4; c++) {
		voltages_acc_cur[c] = 0;
		l600_current_acc[c] = 0;
		l600_voltages_acc[c] = 0;
	}
	l600_current_count = 0;

	IPR1 = 0;
	IPR2 = 0;
	IPR3 = 0;
	IPR4 = 0;
	IPR5 = 0;
	IPR6 = 0;
	IPR7 = 0;
	IPR8 = 0;
	IPR9 = 0;
	IPR10 = 0;
	IPR11 = 0;
	IPR12 = 0;
	IPR13 = 0;
	IPR14 = 0;
	IPR15 = 0;
	INTCON0 = 0;
	INTCON1 = 0;
	INTCON0bits.IPEN=1; /* enable interrupt priority */

	USART_INIT(0);

	/* configure timer0 as free-running counter at 9.765625Khz * 4 */
	T0CON0 = 0x0;
	T0CON0bits.MD16 = 1; /* 16 bits */
	T0CON1 = 0x48; /* 01001000 Fosc/4, sync, 1/256 prescale */
	PIR3bits.TMR0IF = 0;
	PIE3bits.TMR0IE = 0; /* no interrupt */
	T0CON0bits.T0EN = 1;

#ifdef USE_TIMER2
	/* configure timer2 for 250Hz interrupt */
	T2CON = 0x44; /* b01000100: postscaller 1/5, prescaler 1/16 */
	T2PR = 125; /* 250hz output */
	T2CLKCON = 0x01; /* Fosc / 4 */
	T2CONbits.TMR2ON = 1;
	PIR3bits.TMR2IF = 0;
	IPR3bits.TMR2IP = 1; /* high priority interrupt */
	PIE3bits.TMR2IE = 1;
#else
	/* configure UTMR for 10Hz interrupt */
	TU16ACON0 = 0x04; /* period match IE */
	TU16ACON1 = 0x00;
	TU16AHLT = 0x00; /* can't use hardware reset because of HW bug */
	TU16APS = 249; /* prescaler = 250 -> 40000 Hz */
	TU16APRH = (4000 >> 8) & 0xff;
	TU16APRL = 4000 & 0xff;
	TU16ACLK = 0x2; /* Fosc */
	TUCHAIN = 0;
	TU16ACON0bits.ON = 1;
	TU16ACON1bits.CLR = 1;
	IPR0bits.TU16AIP = 1; /* high priority interrupt */
	PIE0bits.TU16AIE = 1;
#endif

	I2C_INIT;

	INTCON0bits.GIEH=1;  /* enable high-priority interrupts */   
	INTCON0bits.GIEL=1; /* enable low-priority interrrupts */   

	LEDBATT_G = 1;

	printf("hello user_id 0x%lx devid 0x%x revid 0x%x\n", nmea2000_user_id, devid, revid);
	LEDBATT_R = 0;

	printf("n2k_init\n");
	nmea2000_init();
	poll_count = timer0_read();

	/* enable watchdog */
	WDTCON0bits.SEN = 1;

	/* set up ADC */
	PIR1bits.ADIF = 0;
	ADCON0 = 0x4; /* right-justified */
	ADCON1 = 0; /* no cap */
	ADCON2 = 0; /* basic mode */
	ADCON3 = 0; /* basic mode */
	ADCLK = 7; /* Fosc/16 */
	ADREF = 0;  /* vref = VDD */
	ADPCH = 0; /* channel 0 */
	ADACQH = 0;
	ADACQL = 20; /* 20Tad Aq */
	ADCON0bits.ADON = 1;

	c = 0;
	NDOWN = 1;

	/* wait 50ms for pac1953 to be up */
	for (c = 0; c < 50; c++) {
		t0 = timer0_read();
		while (timer0_read() - t0 < TIMER0_1MS) {
			; /* wait */
		}
	}

#if 0
	log_erase();
#endif

	/* look for current block */
	printf("blocks");
	for (c = 0; c < LOG_BLOCKS; c++) {
		printf(" 0x%x", battlog[c].b_flags);
		if ((battlog[c].b_flags & B_FILL_STAT) == B_FILL_PART) {
			/* found it */
			log_cblk = c;
			log_gen = battlog[c].b_flags & B_FILL_GEN;
			break;
		}
		if ((battlog[c].b_flags & B_FILL_STAT) == B_FILL_FULL) {
			uint8_t c2 = (c + 1) & LOG_BLOCKS_MASK;
			if ((battlog[c2].b_flags & B_FILL_STAT)
			    == B_FILL_FREE) {
				/* stopped just at boundary */
				log_cblk = c2;
				log_gen = battlog[c].b_flags & B_FILL_GEN;
				if (log_cblk == 0)
					log_gen += 0x4;
				break;
			}
		}
	}
	printf("\n");
	if (c == LOG_BLOCKS) {
		/* log empty, start a 0 */
		printf("log empty\n");
		log_cblk = 0;
		log_gen = 0;
	}
	/* look for first free entry in block */
	for (c = 0; c < LOG_ENTRIES; c++) {
		if (battlog[log_cblk].b_entry[c].s.nvalid == 1) {
			/* first free entry */
			log_centry = c;
			break;
		}
	}
	if (c == LOG_ENTRIES) {
		/* log corrupted, reset */
		printf("non-full block with no free entry: reset log\n");
		log_erase();
	}
	page_read(&battlog[log_cblk]);

	memset(&curlog.b_entry[log_centry], 0, sizeof(union log_entry));

	next_log_entry();

	LEDBATT_R = LEDBATT_G = 0;

again:
	c = 0;
	if (i2c_readreg(PAC_I2C_ADDR, PAC_PRODUCT, &i2cr, 1) != 1)
		c++;
	else 
		printf("product id 0x%x ", i2cr);

	if (i2c_readreg(PAC_I2C_ADDR, PAC_MANUF, &i2cr, 1) != 1)
		c++;
	else
		printf("manuf id 0x%x ", i2cr);

	if (i2c_readreg(PAC_I2C_ADDR, PAC_REV, &i2cr, 1) != 1)
		c++;
	else
		printf("rev id 0x%x\n", i2cr);

	if (i2c_readreg(PAC_I2C_ADDR,
	    PAC_CTRL_ACT, (uint8_t *)&pac_ctrl, sizeof(pac_ctrl)) !=
	    sizeof(pac_ctrl))
		c++;
	else {
		printf("CTRL_ACT al1 %d al2 %d mode %d dis %d\n",
		    pac_ctrl.ctrl_alert1,
		    pac_ctrl.ctrl_alert2,
		    pac_ctrl.ctrl_mode,
		    pac_ctrl.ctrl_chan_dis);
	}

	pac_ctrl.ctrl_alert1 = pac_ctrl.ctrl_alert2 = CTRL_ALERT_ALERT;
	pac_ctrl.ctrl_mode = CTRL_MODE_1024;

	if (i2c_writereg(PAC_I2C_ADDR,
	    PAC_CTRL, (uint8_t *)&pac_ctrl, sizeof(pac_ctrl)) == 0) {
		printf("wr PAC_CTRL fail\n");
		c++;
	}

	pac_accumcfg.accumcfg_acc1 = ACCUMCFG_VSENSE;
	pac_accumcfg.accumcfg_acc2 = ACCUMCFG_VSENSE;
	pac_accumcfg.accumcfg_acc3 = ACCUMCFG_VSENSE;
	pac_accumcfg.accumcfg_acc4 = ACCUMCFG_VSENSE;
	if (i2c_writereg(PAC_I2C_ADDR,
	    PAC_ACCUMCFG, (uint8_t *)&pac_accumcfg, sizeof(pac_accumcfg)) == 0) {
		printf("wr PAC_ACCUMCFG fail\n");
		c++;
	}

	pac_neg_pwr_fsr.pwrfsr_vb1 = pac_neg_pwr_fsr.pwrfsr_vs1 = PAC_PWRSFR_BHALF;
	pac_neg_pwr_fsr.pwrfsr_vb2 = pac_neg_pwr_fsr.pwrfsr_vs2 = PAC_PWRSFR_BHALF;
	pac_neg_pwr_fsr.pwrfsr_vb3 = pac_neg_pwr_fsr.pwrfsr_vs3 = PAC_PWRSFR_BHALF;
	pac_neg_pwr_fsr.pwrfsr_vb4 = pac_neg_pwr_fsr.pwrfsr_vs4 = PAC_PWRSFR_BHALF;
	if (i2c_writereg(PAC_I2C_ADDR,
	    PAC_NEG_PWR_FSR, (uint8_t *)&pac_neg_pwr_fsr,
	    sizeof(pac_neg_pwr_fsr)) == 0) {
		printf("wr PAC_NEG_PWR_FSR fail\n");
		c++;
	}

	if (i2c_writecmd(PAC_I2C_ADDR, PAC_REFRESH) == 0) {
		printf("cmd PAC_REFRESH fail\n");
		c++;
	}
	if (c != 0)
		goto again;

	while (1) {
		CLRWDT();
		if (C1INTLbits.RXIF) {
			nmea2000_receive();
		}
		if (NCANOK) {
			nmea2000_status = NMEA2000_S_ABORT;
			poll_count = timer0_read();;
		} else if (nmea2000_status != NMEA2000_S_OK) {
			uint16_t ticks, tmrv;

			tmrv = timer0_read();
			ticks = tmrv - poll_count;
			if (ticks > TIMER0_5MS) {
				poll_count = tmrv;
				nmea2000_poll(ticks / TIMER0_1MS);
			}
			if (nmea2000_status == NMEA2000_S_OK) {
				printf("new addr %d\n", nmea2000_addr);
			}
		}
		if (PIR1bits.ADIF) {
			PIR1bits.ADIF = 0;
			a2d_acc = ((unsigned int)ADRESH << 8) | ADRESL;
			switch (ADPCH) {
			case 0:
				/* channel 0: NTC */
				adctotemp(0);
				ADCON0bits.ADON = 0;
				ADPCH = 1;
				ADCON0bits.ADON = 1;
				break;
			case 1:
				/* channel 1: NTC */
				adctotemp(1);
				ADCON0bits.ADON = 0;
				ADPCH = 4;
				ADCON0bits.ADON = 1;
				break;
			case 4:
				/* channel 4: NTC */
				adctotemp(2);
				ADCON0bits.ADON = 0;
				ADPCH = 0;
				/* don't set ADON, will do on next second */
				break;
			default:
				printf("unknown channel 0x%x\n", ADCON0);
			}
		}
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

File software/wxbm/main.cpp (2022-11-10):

/*
 * Copyright (c) 2019 Manuel Bouyer
 *
 * All rights reserved.
 *
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
 * THIS SOFTWARE IS PROVIDED BY THE NETBSD FOUNDATION, INC. AND CONTRIBUTORS
 * ``AS IS'' AND ANY EXPRESS OR IMPLIED WARRANTIES, INCLUDING, BUT NOT LIMITED
 * TO, THE IMPLIED WARRANTIES OF MERCHANTABILITY AND FITNESS FOR A PARTICULAR
 * PURPOSE ARE DISCLAIMED.  IN NO EVENT SHALL THE FOUNDATION OR CONTRIBUTORS
 * BE LIABLE FOR ANY DIRECT, INDIRECT, INCIDENTAL, SPECIAL, EXEMPLARY, OR
 * CONSEQUENTIAL DAMAGES (INCLUDING, BUT NOT LIMITED TO, PROCUREMENT OF
 * SUBSTITUTE GOODS OR SERVICES; LOSS OF USE, DATA, OR PROFITS; OR BUSINESS
 * INTERRUPTION) HOWEVER CAUSED AND ON ANY THEORY OF LIABILITY, WHETHER IN
 * CONTRACT, STRICT LIABILITY, OR TORT (INCLUDING NEGLIGENCE OR OTHERWISE)
 * ARISING IN ANY WAY OUT OF THE USE OF THIS SOFTWARE, EVEN IF ADVISED OF THE
 * POSSIBILITY OF SUCH DAMAGE.
 */

#include <wx/wx.h>
#include <wx/config.h>
#include <wx/cmdline.h>
#include "wxbm.h"
#include "bmstatus.h"
#include "bmlog.h"
#include "icons/icons8-car-battery-30.xpm"
#include <N2K/NMEA2000.h>
#include <N2K/NMEA2000Properties.h>
#include <N2K/NMEA2000PropertiesDialog.h>

#ifdef DEBUG            
#define DBG(a) {a;}
#else
#define DBG(a) /* */
#endif

const int myID_F_N2KCONF =	wxID_HIGHEST + 10;
const int myID_F_PLOAD =	wxID_HIGHEST + 11;
const int myID_F_PSAVE =	wxID_HIGHEST + 12;
const int myID_F_SHOWLOG =	wxID_HIGHEST + 13;
const int myID_DATAUP =		wxID_HIGHEST + 100;

class bmFrame : public wxFrame
{
public:
	bmFrame(const wxString& title);
	typedef enum dataup {
		data_values = 0,
		data_status,
	} dataup_t;
	void wake(dataup_t);
	int addr;
	int group;
	wxString mode;
	double volts[NINST];
	double amps[NINST];
	double temp[NINST];
	bool instV[NINST];

private:
	wxPanel *mainpanel;
	wxBoxSizer *mainsizer;
	wxMenuBar *menubar;
	wxMenu *file;
	wxMenu *view;
	bmStatus *bmstatus;

	void OnN2KConfig(wxCommandEvent & event);
	void OnDataUpdate(wxCommandEvent & event);
	void OnQuit(wxCommandEvent & event);
	void OnClose(wxCloseEvent & event);
	void OnShowLog(wxCommandEvent & event);
};

bmFrame::bmFrame(const wxString& title)
	: wxFrame(NULL, wxID_ANY, title)
{
	int x, y, w, h;

	wxConfig *config = wxp->getConfig();
	if (config) {
		x = config->ReadLong("/Position/X", -1);
		y = config->ReadLong("/Position/Y", -1);
		w = config->ReadLong("/Position/W", -1);
		h = config->ReadLong("/Position/H", -1);
	} else {
		x = y = w = h = -1;
	}
	for (int i = 0; i < NINST; i++)
		instV[i] = false;
	nmea2000P = new nmea2000;
	NMEA2000PropertiesP = new NMEA2000Properties(config);
	//mainpanel = new wxPanel(this, wxID_ANY);
	mainsizer = new wxBoxSizer( wxVERTICAL );
	menubar = new wxMenuBar;
	file = new wxMenu;
	file->Append(myID_F_N2KCONF, _T("N2k Config"));
	file->Append(wxID_EXIT, _T("&Quit"));
	menubar->Append(file, _T("&File"));
	view = new wxMenu;
	view->Append(myID_F_SHOWLOG, _T("&Log\tCTRL+L"));
	menubar->Append(view, _T("&View"));
	SetMenuBar(menubar);
	Connect(wxEVT_CLOSE_WINDOW,
		wxCloseEventHandler(bmFrame::OnClose));
	Connect(myID_F_N2KCONF, wxEVT_COMMAND_MENU_SELECTED,
		wxCommandEventHandler(bmFrame::OnN2KConfig));
	Connect(wxID_EXIT, wxEVT_COMMAND_MENU_SELECTED,
		wxCommandEventHandler(bmFrame::OnQuit));
	Connect(myID_DATAUP, wxEVT_COMMAND_TEXT_UPDATED,
		wxCommandEventHandler(bmFrame::OnDataUpdate));
	Connect(myID_F_SHOWLOG, wxEVT_COMMAND_MENU_SELECTED,
		wxCommandEventHandler(bmFrame::OnShowLog));

	bmstatus = new bmStatus(this);
	mainsizer->Add( bmstatus, 0, wxEXPAND | wxALL, 5 );

	SetSizerAndFit(mainsizer);
	this->SetSize(x, y, w, h);

	wxp->bmlog = new bmLog(this);
	wxIcon icon(icons8_car_battery_30);
	wxp->bmlog->SetIcon(icon);
	wxp->bmlog->Show(false);
}

void bmFrame::OnN2KConfig(wxCommandEvent & WXUNUSED(event))
{
	NMEA2000PropertiesDialog *N2KPropDialog = new NMEA2000PropertiesDialog(this, wxp->getBmAddress());
	N2KPropDialog->ShowModal();
	delete N2KPropDialog;

}

void bmFrame::wake(dataup_t t)
{
	wxCommandEvent event(wxEVT_COMMAND_TEXT_UPDATED, myID_DATAUP);
	event.SetInt(t);
	GetEventHandler()->AddPendingEvent( event );
}

void bmFrame::OnDataUpdate(wxCommandEvent & event)
{
	dataup_t t;
	t = (dataup_t)event.GetInt();
	switch(t) {
	case bmFrame::dataup_t::data_status:
		bmstatus->address(addr);
		break;
	case bmFrame::dataup_t::data_values:
		for (int i = 0; i < NINST; i++) {
			bmstatus->values(i, volts[i], amps[i],
			    temp[i], instV[i]);
		}
		break;
	}
}

void bmFrame::OnQuit(wxCommandEvent & WXUNUSED(event))
{
	Close(true);
}

void bmFrame::OnClose(wxCloseEvent & event)
{
	wxConfig *config = wxp->getConfig();
	if (config) {
		int x, y, w, h;
		GetClientSize(&w, &h);
		GetPosition(&x, &y);
		config->Write(_T("/Position/x"), (long) x);
		config->Write(_T("/Position/y"), (long) y);
		config->Write(_T("/Position/w"), (long) w);
		config->Write(_T("/Position/h"), (long) h);
		wxp->bmlog->GetClientSize(&w, &h);
		wxp->bmlog->GetPosition(&x, &y);
		config->Write(_T("/Log/x"), (long) x);
		config->Write(_T("/Log/y"), (long) y);
		config->Write(_T("/Log/w"), (long) w);
		config->Write(_T("/Log/h"), (long) h);
		config->Flush();
		std::cout <<  "saved config file ... " << std::endl;
	}
	delete nmea2000P;
	std::cout <<  "Exiting ... " << std::endl;
	event.Skip();
}

void bmFrame::OnShowLog(wxCommandEvent & WXUNUSED(event))
{

	DBG(std::cout <<  "show log ... " << std::endl);
	wxp->bmlog->Show(true);

}

static const wxCmdLineEntryDesc g_cmdLineDesc [] =
{
	{ wxCMD_LINE_SWITCH, "h", "help",
	    "displays help on the command line parameters",
	    wxCMD_LINE_VAL_NONE, wxCMD_LINE_OPTION_HELP },
	{ wxCMD_LINE_SWITCH, "L", "nolog",
	    "disables reading log from device"},
	{ wxCMD_LINE_NONE }
};

IMPLEMENT_APP(wxbm)

wxbm *wxp;

bool wxbm::OnInit()
{
	if (!wxApp::OnInit())
		return false;

	config = new wxConfig(AppName());
	wxIcon icon(icons8_car_battery_30);
	int conf_valid = 0;
	wxString path;

	wxp = this;

	for(int i = 0; i < NINST; i++) {
		if (config) {
			path = wxString::Format(wxT("/Instance/%d"), i);
			if (config->Read(path, &Tname[i])) {
				conf_valid++;
			}
		}
	}
	if (conf_valid == 0 && config) {
		for(int i = 0; i < NINST; i++) {
			Tname[i] = wxString::Format(wxT("string:%d"), i);
			path = wxString::Format(wxT("/Instance/%d"), i);
			config->Write(path, Tname[i]);
		}
	}

	frame = new bmFrame(AppName());
	frame->SetIcon(icon);
	frame->Show(true);
	nmea2000P->Init();
	bmAddress = -1;

	return true;
}

void wxbm::OnInitCmdLine(wxCmdLineParser& parser)
{
	parser.SetDesc (g_cmdLineDesc);
	parser.SetSwitchChars (_T("-"));
}

bool wxbm::OnCmdLineParsed(wxCmdLineParser& parser)
{
	getlog = !parser.Found(_T("L"));
	if (!getlog)
		printf("log disabled\n");
	return true;
}

#define APPNAME "wxbm"

wxString wxbm::AppName()
{
	static wxString s(APPNAME);
	return s;
}
wxString wxbm::ErrMsgPrefix()
{
	static wxString s(APPNAME ": ");
	return s;
}
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

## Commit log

2021-12-12 Initial commit of hardware kicad files, ready for first rev production
    [battery_can_monitor.kicad_pcb, battery_can_monitor.sch, osculati_amperemetre_sensor.kicad_pcb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]
2021-12-13 Restore proper hole size for RJ45 connectors.
    [battery_can_monitor.kicad_pcb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]
2021-12-13 Keep coating on the front side for through-hole connectors pads (we can't solder them anyway)
    [battery_can_monitor.kicad_pcb]
2021-12-13 Add mask/paste fabrication files
    [osculati_amperemetre_sensor.kicad_pcb]
2021-12-20 Add a 6mm margin around PCB.
    [battery_can_monitor.kicad_pcb, osculati_amperemetre_sensor.kicad_pcb]
2021-12-20 Regen fabrication outputs.
    [battery_can_monitor.kicad_pcb, osculati_amperemetre_sensor.kicad_pcb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]
2022-01-28 Fix name of connectors (sense1/sense2 swapped)
    [battery_can_monitor.kicad_pcb, battery_can_monitor.sch]
2022-02-01 Test version of the canbus battery monitor software. Lots of functions missing but good enough to test main functionalities (pic18, pac1953, CAN)
    [main.c]
2022-02-06 Read voltage on all channels every 1/10s. Read accum, and compute average voltage and current for all channels every seconds.
2022-02-06 Use the disable bit from ctrl register to skip channels.
    [main.c]
2022-02-07 Reorganise reading values from the pac195x. Send battery_status one per second, one instance every 10ms.
2022-02-13 Update fabrication files.
    [battery_can_monitor-B_Cu.gbr, battery_can_monitor-F_Cu.gbr, battery_can_monitor.drl]
2022-02-13 Properly use the NCANOK signal to manage the can bus.
2022-02-13 swap green & red LEDs to match hardware.
    [main.c]
2022-02-16 Add mounting holes dimentions
    [battery_can_monitor.kicad_pcb, osculati_amperemetre_sensor.kicad_pcb]
2022-02-16 Tie floating pins to GND. Get temperatures from thermistors.
2022-02-18 Add drawings for the box holding the PCBs
    [battery_can_monitor-F_Cu.dxf, osculati_amperemetre_sensor-B_Cu.dxf]
2022-03-06 Correct results with calibration data.
    [main.c]
2022-04-03 Add a log (in flash) to keep track of battery voltage/current/temperature.
2022-04-05 WIP on a battery status app
2022-04-10 Fix invalid temp in log
    [main.c]
2022-04-10 Fix temperature in log packet
    [main.c]
2022-04-10 WIP: request and print log from BM.
2022-04-10 Make sure to not count duplicate frames
2022-06-22 Add some icons from Icons8, and use the car battery as the app icon
2022-07-03 If the temperature is very low, assume there's no sensor
2022-07-03 If we need to resend a command, also reset the current index
2022-09-07 bmlogstorage: add support to get current, next of previous block
2022-09-07 Trace all 3 graphs
2022-09-08 log: another debug printf, print the interval between log entries.
2022-09-08 Redefine mpScaleX for something more appropriate for our use case.
2022-09-08 Use localtime for X axis
2022-09-08 bmScaleX: use red for label sticks try to use tick intervals that make sense (multiple of days, hours or 30mn when appropriate)
2022-09-08 Improve temperature display
2022-09-08 invert current sign in displays, > 0 is charging and < 0 discharging.
2022-09-08 Abuse bmScaleX::Plot() to send an event when scale or position may have changed. Use this to sync the X view on all 3 plots.
2022-09-09 Set icon for the bmlog frame too.
2022-09-11 In addition to Ah, also print average current
2022-09-11 remove debug printf
2022-09-12 bmlog: start implemnting a top bar with prev/next buttons, zoom setting and time range information
2022-09-13 Make the previous/next buttons navigate in the current block
2022-09-13 Shut up debug printfs
2022-09-13 Add a Fit button
2022-09-14 Don't sleep if we have more work to do (softintrs != 0). Should fix timer drift.
    [main.c]
2022-09-15 Remove debug printf Adjust graph margins
2022-09-17 If we get a PRIVATE_LOG_REPLY frame with no entry, signal it as PRIVATE_LOG_ERROR_LAST. Avoids repeated timeout when the last entry happens to be at the end of a log block.
2022-09-18 Split out log block complete handling out of addLogEntry, so that it's possible to signal a block complete without adding an entry; as is the case when we get a log packet with no entries. PRIVATE_LO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
2022-11-14 Fix amps assembly from log messages.

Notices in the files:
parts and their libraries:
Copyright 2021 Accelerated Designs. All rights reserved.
